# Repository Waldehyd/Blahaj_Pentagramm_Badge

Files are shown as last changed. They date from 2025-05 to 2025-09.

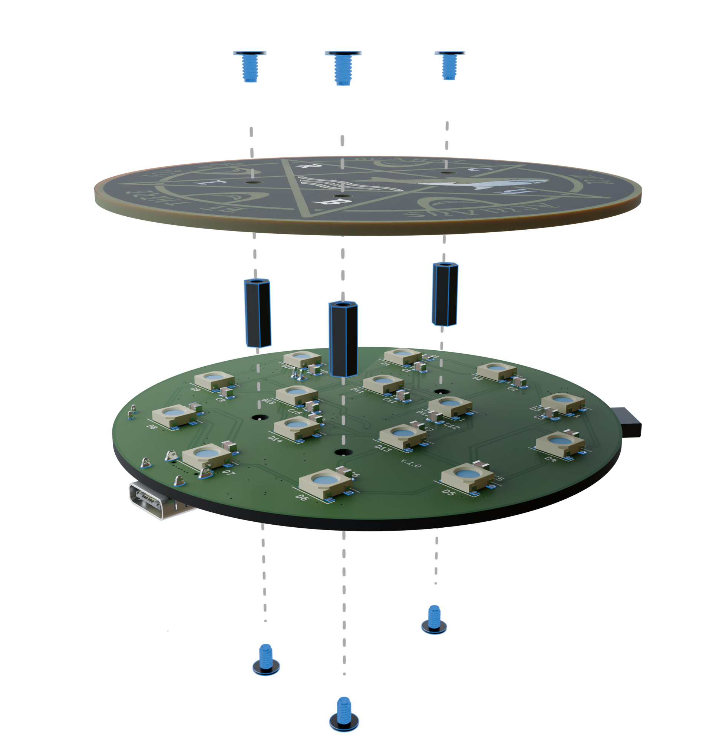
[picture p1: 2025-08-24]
Manual/SetupGuide/Images/Standoffs.png

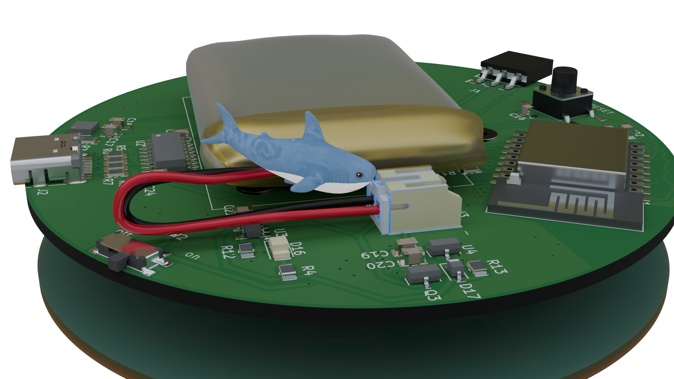
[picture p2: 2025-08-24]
Manual/SetupGuide/Images/AttachLipo.png

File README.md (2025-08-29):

# Blahaj_Pentagramm_Badge

The Shorktagram-Badge features a beautiful PCB-Frontplate backed with 15 individually controllable LEDs, Temperature and Humidity Sensor as well as an optional Motion Sensor. This setup makes it ideal to be used as an air sensor by day and a nightlight by uh... night.

IBOM:
https://htmlpreview.github.io/?https://github.com/Waldehyd/Blahaj_Pentagramm_Badge/blob/main/IBOM/ibom.html

Firmware:

Build WLED (https://github.com/Aircoookie/WLED) using PlatformIO with the following Environment using the Buildflags for BME280 and PIR:

```
[env:d1_mini]
...
build_flags = ${common.build_flags_esp8266} -D USERMOD_BME280 -D USERMOD_PIRSWITCH -D PIR_SENSOR_PIN=13
...
```

Configuration:
```
LED Preferences: 
    -> Length = 15
    -> GPIO = 14
Usermods:
    -> SDA = 4
    -> SCL = 5
    -> Enabled

    Reboot
```

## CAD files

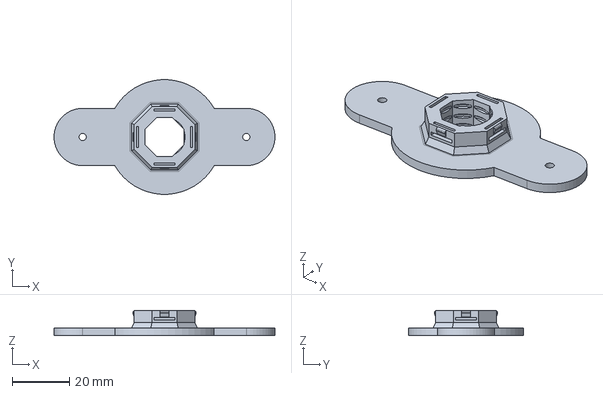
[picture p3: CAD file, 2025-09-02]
Case/mount_multiboard.FCStd
77.0 x 39.9 x 8.80 mm

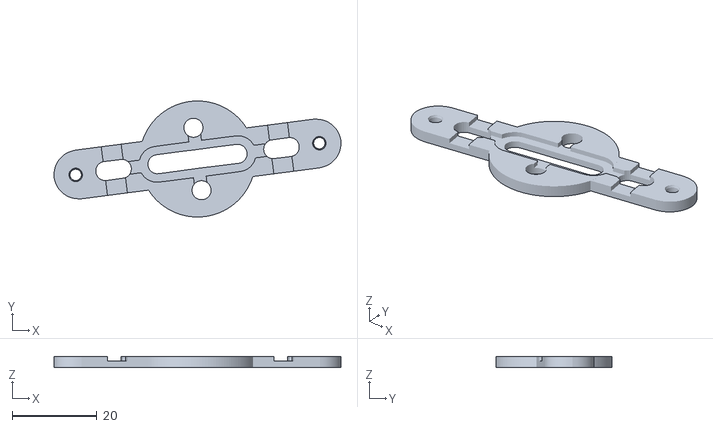
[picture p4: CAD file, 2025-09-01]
Case/STL/Mount.stl
67.6 x 27.3 x 2.51

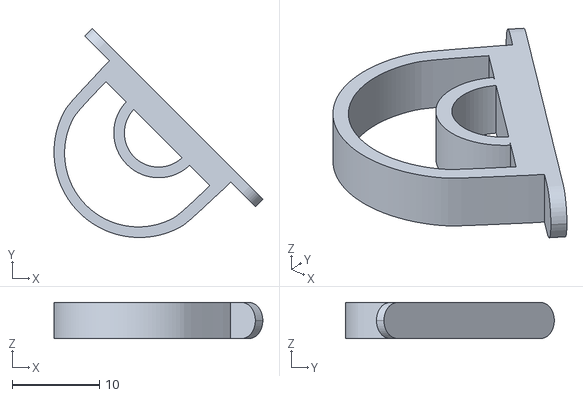
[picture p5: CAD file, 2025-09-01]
Case/STL/Hook.stl
23.9 x 23.9 x 4.15

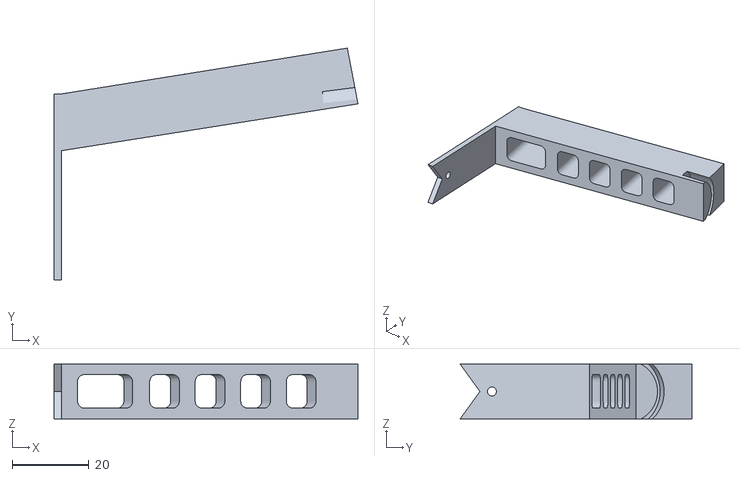
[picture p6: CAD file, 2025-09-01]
Case/STL/Stand_2.stl
79.1 x 60.3 x 14.3

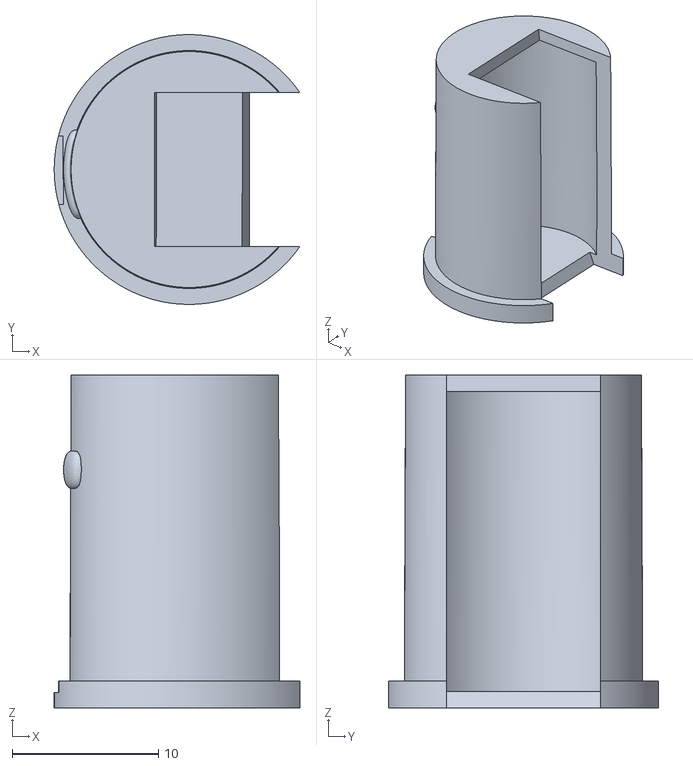
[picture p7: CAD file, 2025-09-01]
Case/STL/PIR_1.stl
16.8 x 18.4 x 22.8

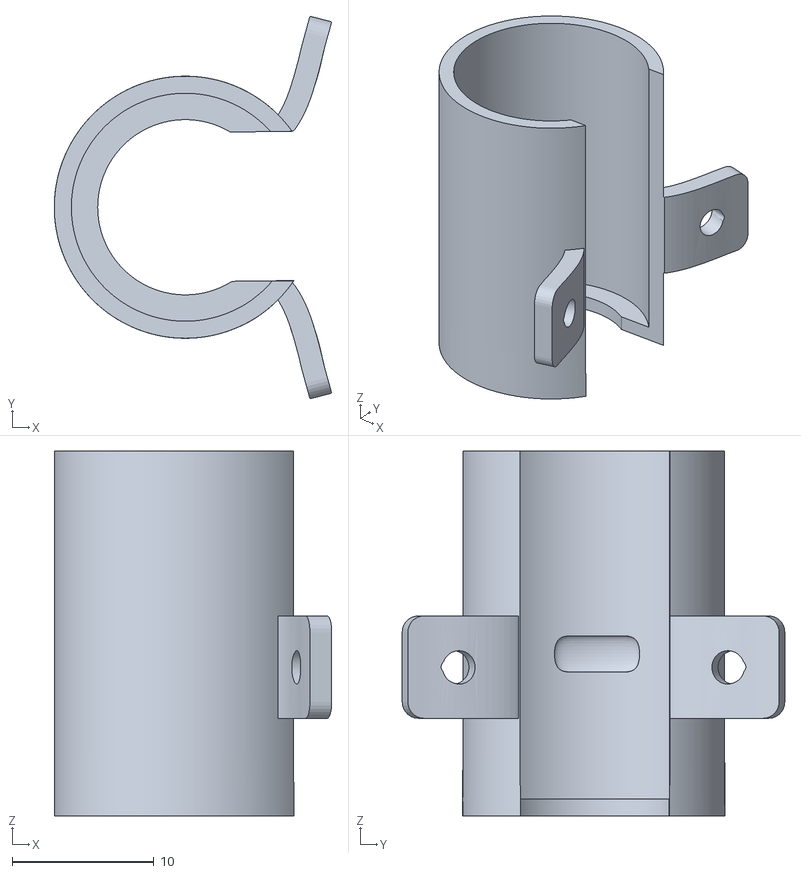
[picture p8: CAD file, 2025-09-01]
Case/STL/PIR_2.stl
19.5 x 26.9 x 25.7

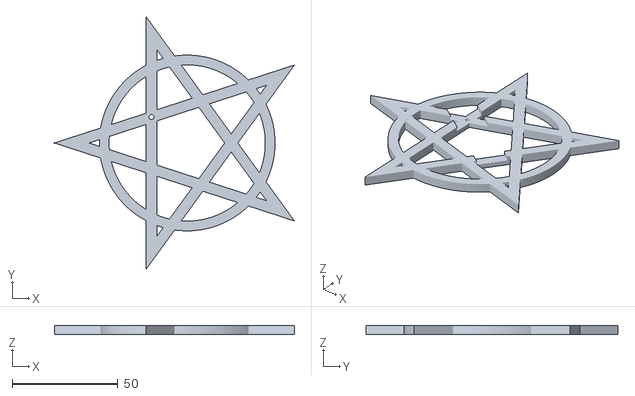
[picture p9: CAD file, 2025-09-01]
Case/STL/Stand_1.stl
113.4 x 119.2 x 4.20

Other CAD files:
Case/STL/mount_multiboard.stl

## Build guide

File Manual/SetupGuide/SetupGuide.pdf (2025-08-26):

Table of Contents

# The Shorktagram Badge

Version 1.0.0 | 2025-08-25 | MIT

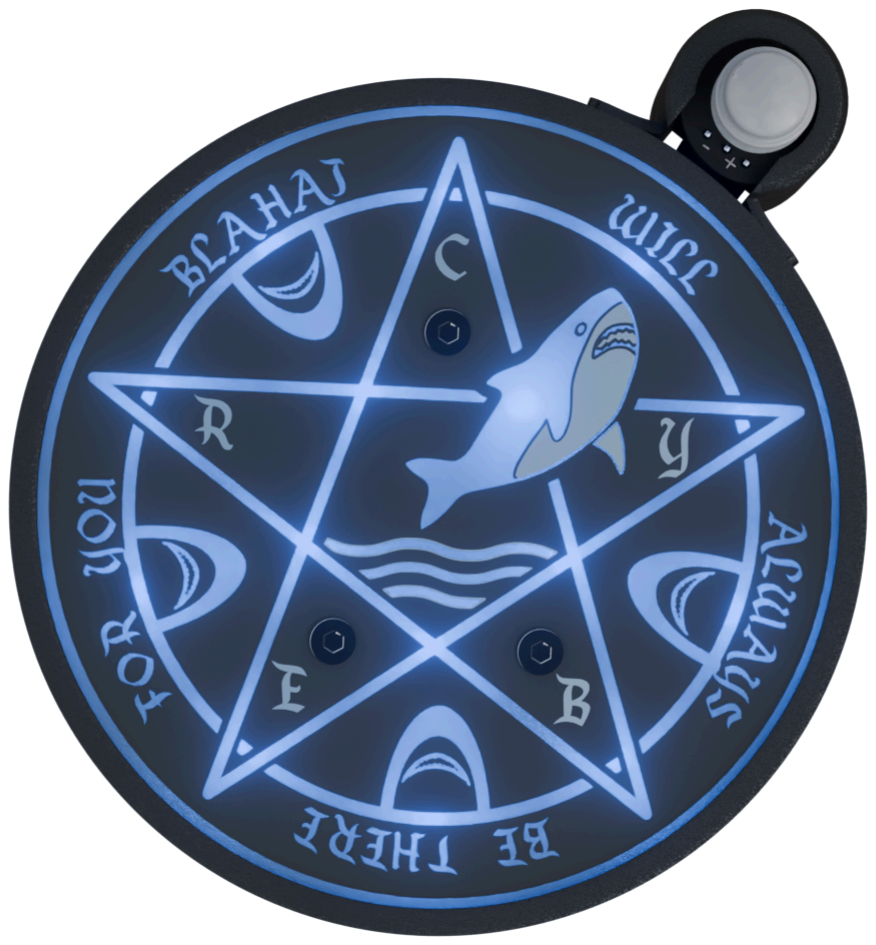
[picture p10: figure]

The Shorktagram-Badge features a beautiful PCB-Frontplate backed with 15 individually controllable LEDs, Temperature and Humidity Sensor as well as an optional Motion Sensor. This setup makes it ideal to be used as an air sensor by day and a nightlight by uh… night.

### Table of Contents

IV.4 Home Assistant Integration and

IV.5 Loading your light settings at

## Part I Assembly Part 1: PCB

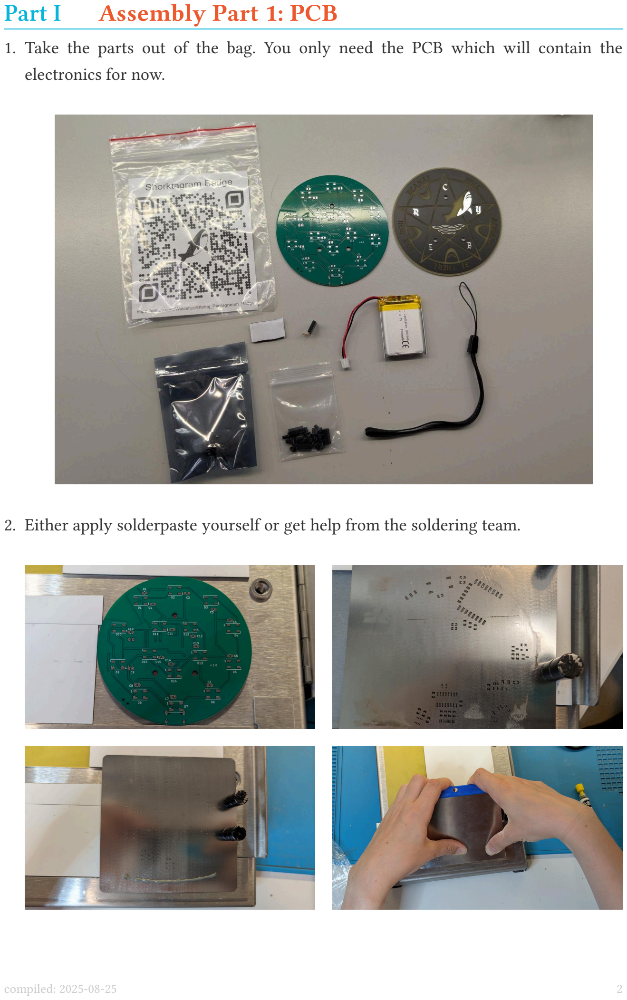
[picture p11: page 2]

1. Take the parts out of the bag. You only need the PCB which will contain the electronics for now.
2. Either apply solderpaste yourself or get help from the soldering team.
compiled: 2025-08-25 | 2

I Assembly Part 1: PCB

3. Open the IBOM of the repo (PCB/PCB_Back/bom/ibom.html) and start placing the parts with a pair of tweezers. The parts in the box are sorted in the order in which they are needed.
4. When you are done with the first side, put the PCB in the oven and bake it for the first time.

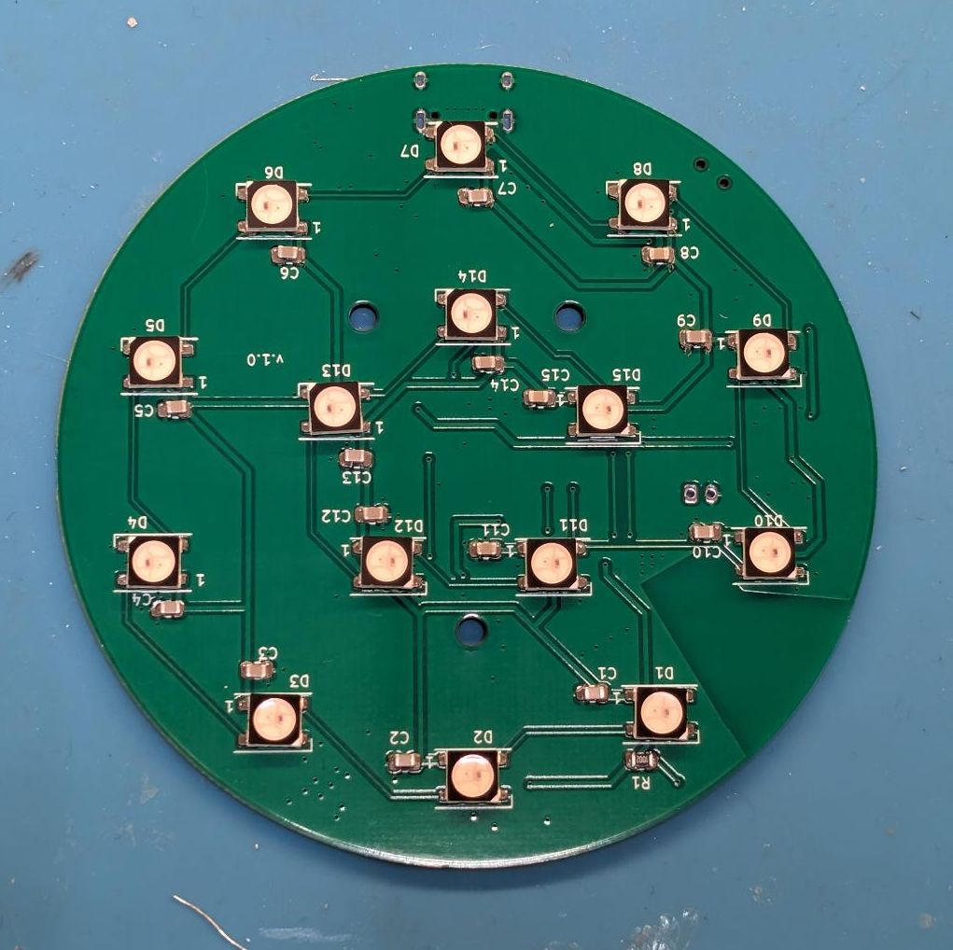
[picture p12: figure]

5. Wait until the PCB has cooled of and continue placing the parts on the other side. Please skip the hand-solder parts for now.
compiled: 2025-08-25 | 3

I Assembly Part 1: PCB

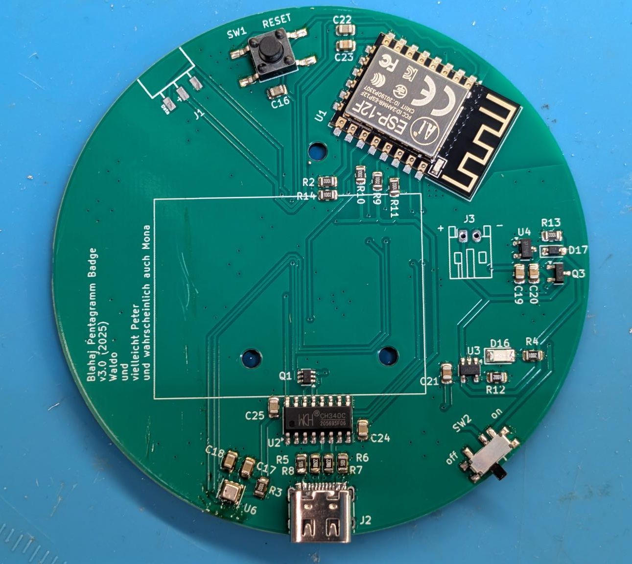
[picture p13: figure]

6. Bake the other side of the PCB.
7. Take a look at the PCB and search for shorts and errors on the placed parts. Remediate these errors before you continue. If needed, get help from your local Shorktagram dealer.
8. Hand-solder the last two parts onto the PCB. Solder on the USB-C connector legs. DO THIS BEFORE YOU PLUG IN A USB CABLE.
9. Connect your PCB to your computer and see if the ESP shows up. If so: Congratulation, you are done with the hardest part. Please return your empty tray to the workshop-hosts. If you want, they can also flash your Shorktagram-Badge.
compiled: 2025-08-25 | 4

## Part II Assembly Part 2: Case

1. Take the little bag with the screws and the standoffs. Screw the faceplate onto the PCB with the standoffs in between.

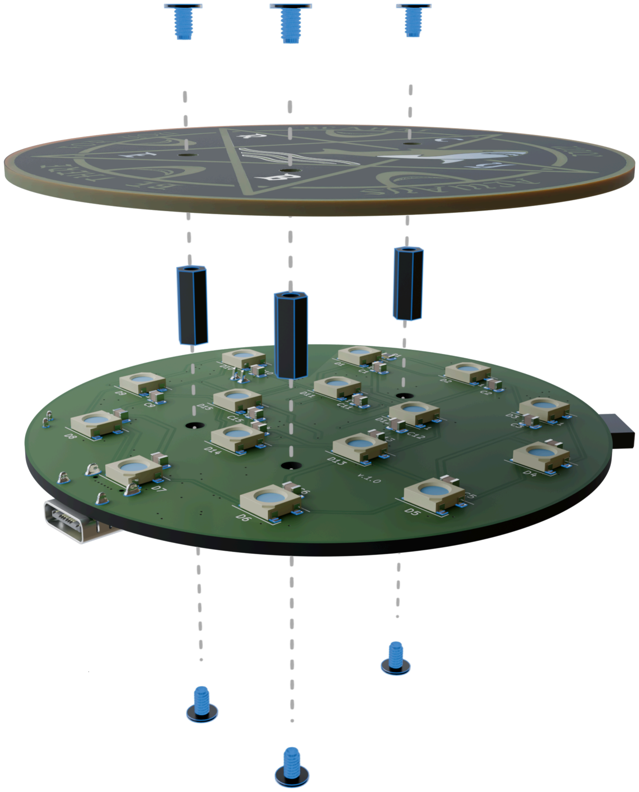
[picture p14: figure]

2. Next you will need the battery and the velcro-tape. If you are planning on using the battery, apply one of the sides of the velcro to the battery-box-area on the PCB and the other side to the battery.

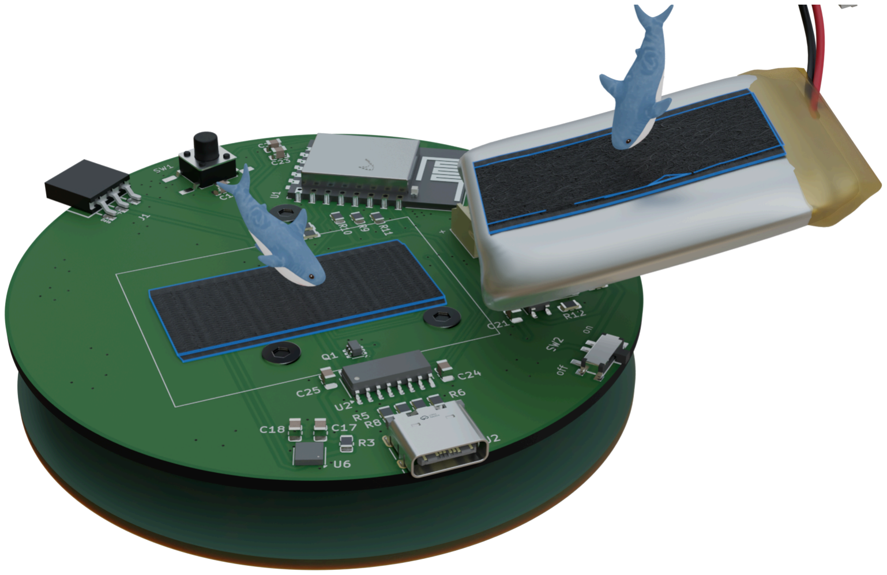
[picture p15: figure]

compiled: 2025-08-25 | 5

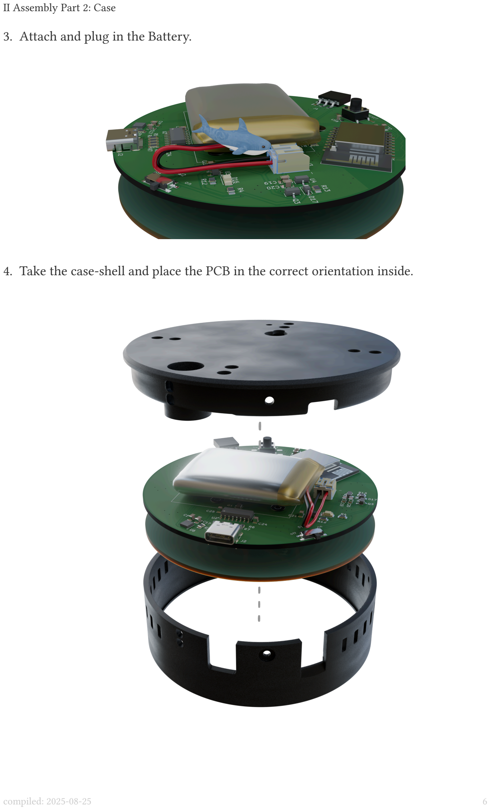
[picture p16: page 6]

II Assembly Part 2: Case

3. Attach and plug in the Battery.
4. Take the case-shell and place the PCB in the correct orientation inside.
compiled: 2025-08-25 | 6

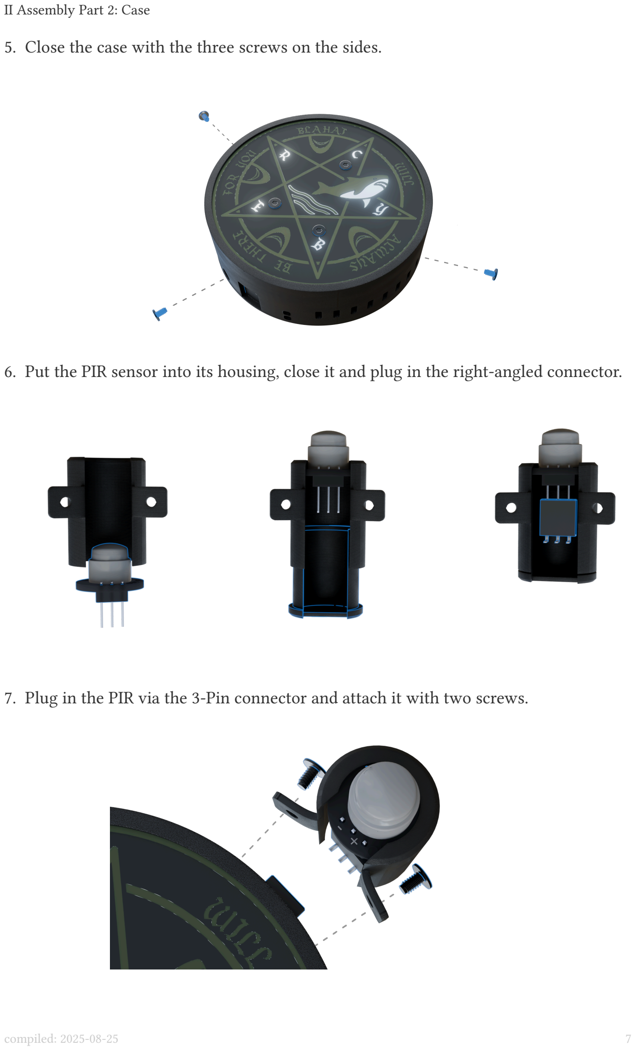
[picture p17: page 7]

II Assembly Part 2: Case

5. Close the case with the three screws on the sides.
6. Put the PIR sensor into its housing, close it and plug in the right-angled connector.
7. Plug in the PIR via the 3-Pin connector and attach it with two screws.
compiled: 2025-08-25 | 7

II Assembly Part 2: Case

8. Screw in two screws into the mounting plate (towards the side with cutouts). Optionally, push through the hook. You attach the mounting plate by pushing and turning them in the oblong holes.

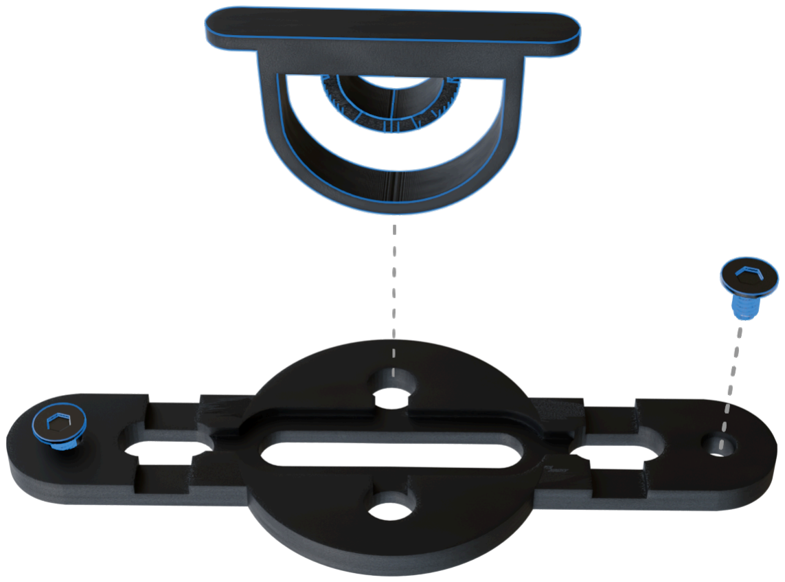
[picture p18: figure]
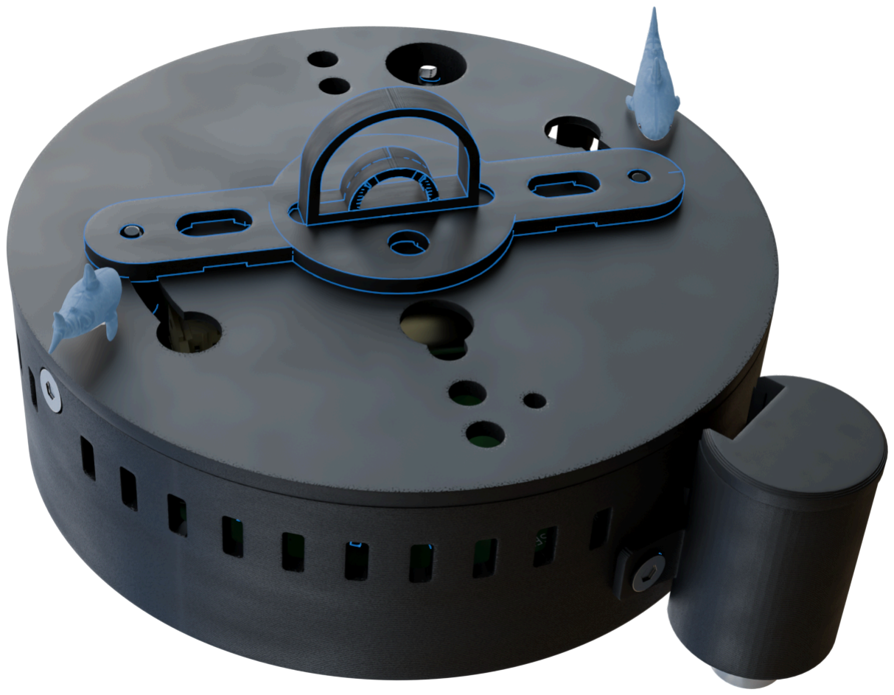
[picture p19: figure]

compiled: 2025-08-25 | 8

## Part III Flashing the Firmware

Prerequisites: A computer running VSCode with the Platform.io extension installed.

The Shorktagram-Badge is powered by WLED. As we use Usermods to support the PIR and the BME280, it’s necessary to build WLED from source. This involves the following steps:

1. Clone or Download the latest Version of WLED from Github (https://github.com/wled/WLED) (https://github.com/wled/WLED)
2. Replace the platformio.ini by the one in the /Firmware folder of the Shorktagram-Badge Repository (https://github.com/Waldehyd/Blahaj_Pentagramm_Badge)
3. Connect the Badge to your computer via USB (if it’s not recognized as a serial device, it’s likely a soldering problem)
4. Open the WLED-Folder in VSCode
5. Choose the correct serial port of your Badge (if multiple devices are connected) and then hit upload!
compiled: 2025-08-25 | 9

## Part IV Configuring WLED

### IV.1 Default Values

After flashing, the 15 LEDs should light up instantly. The following values should be preconfigured and (if correct) should not be edited:

SDA | 4
SCL | 5
PIRPIN | 13
LEDPIN | 14
LEDCOUNT | 15

### IV.2 Wifi-Setup

By default, WLED opens up a Wifi-AP to access the Webinterface. The default password is “wled1234”. To integrate your Badge into your local Wifi, hit “WiFi Setup” and enter your credentials. You can also change the password of the AP from there as well (we recommend this to avoid mix-ups, i.e. connecting to the wrong device).

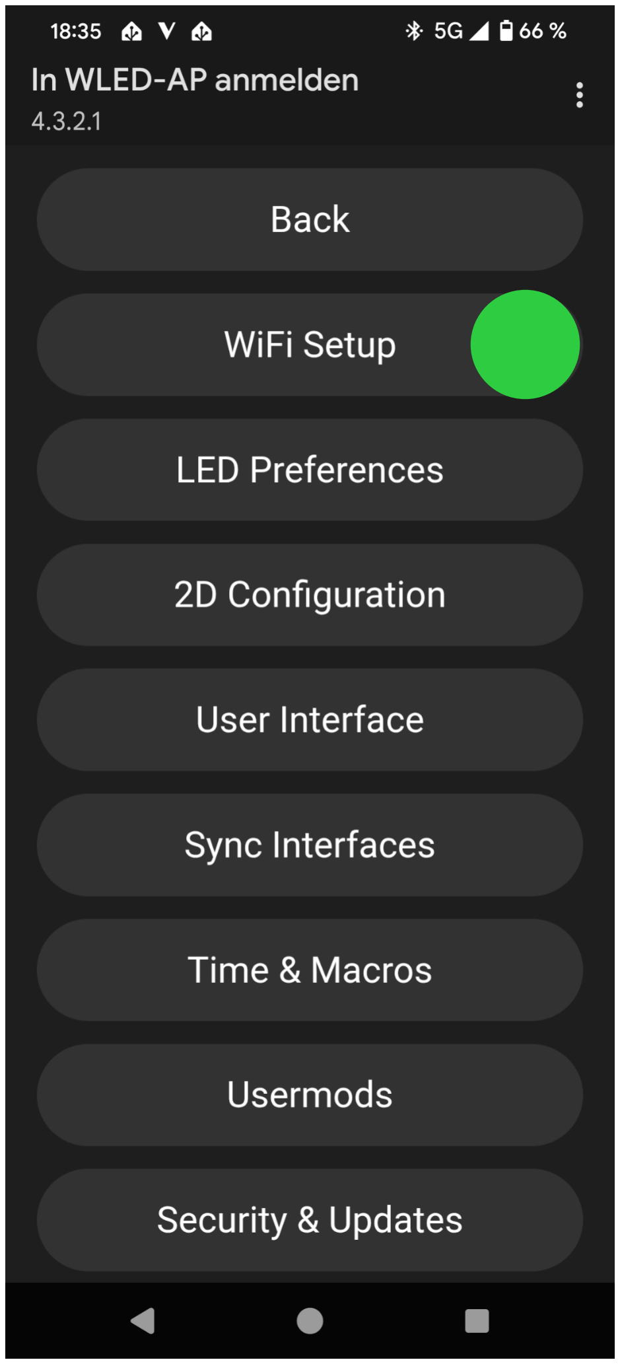
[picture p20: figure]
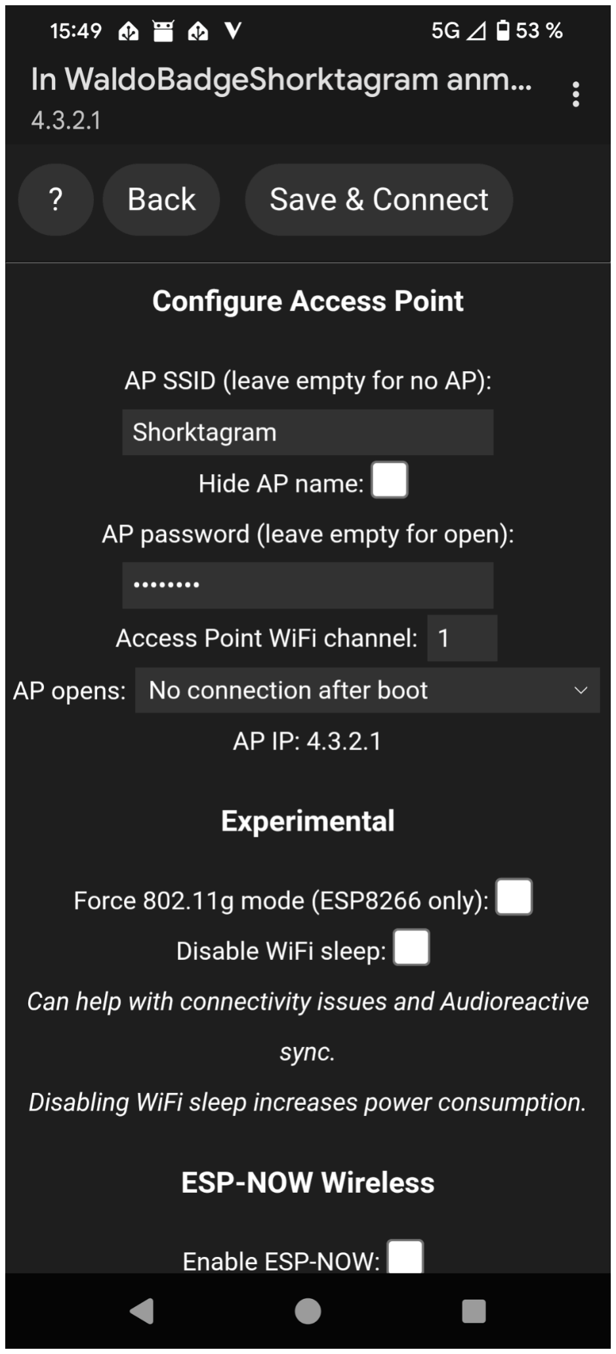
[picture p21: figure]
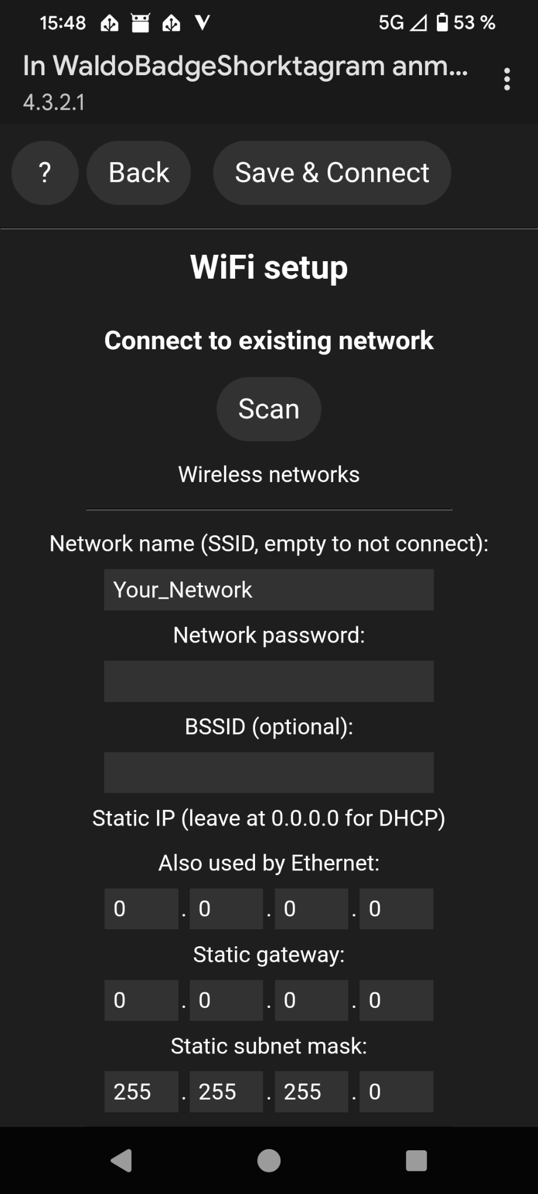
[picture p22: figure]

compiled: 2025-08-25 | 10

IV Configuring WLED

### IV.3 Enable Usermods

Back in the Settings, go to “Usermods”. From there, you can enable the BME280 and/or the PIR.

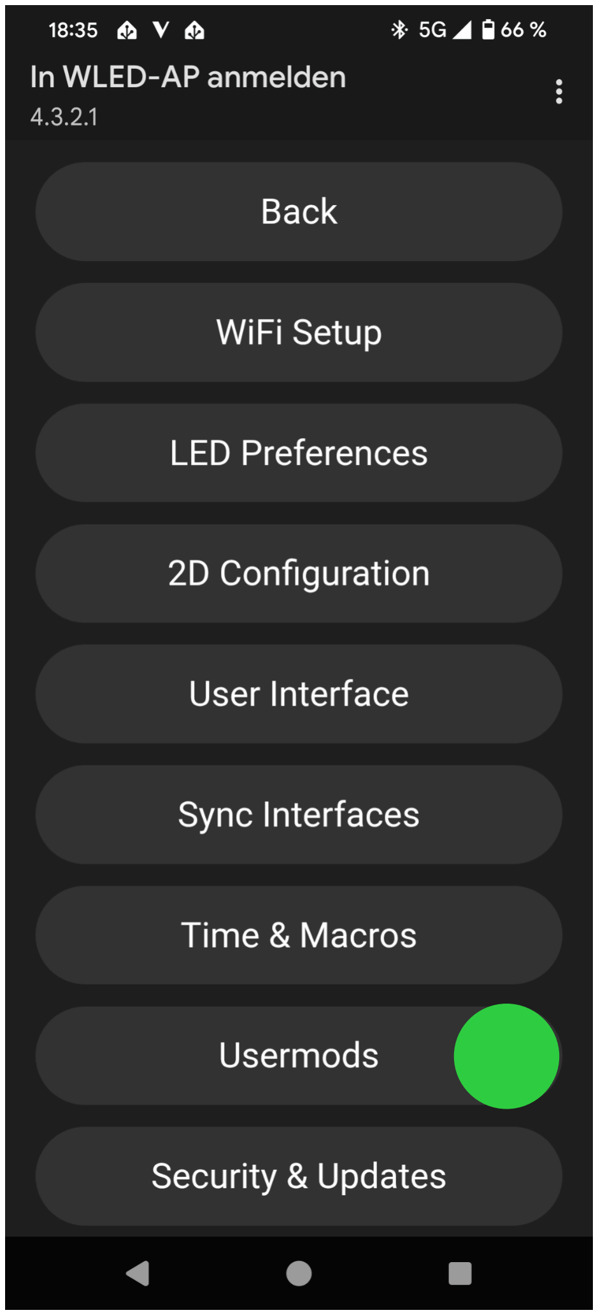
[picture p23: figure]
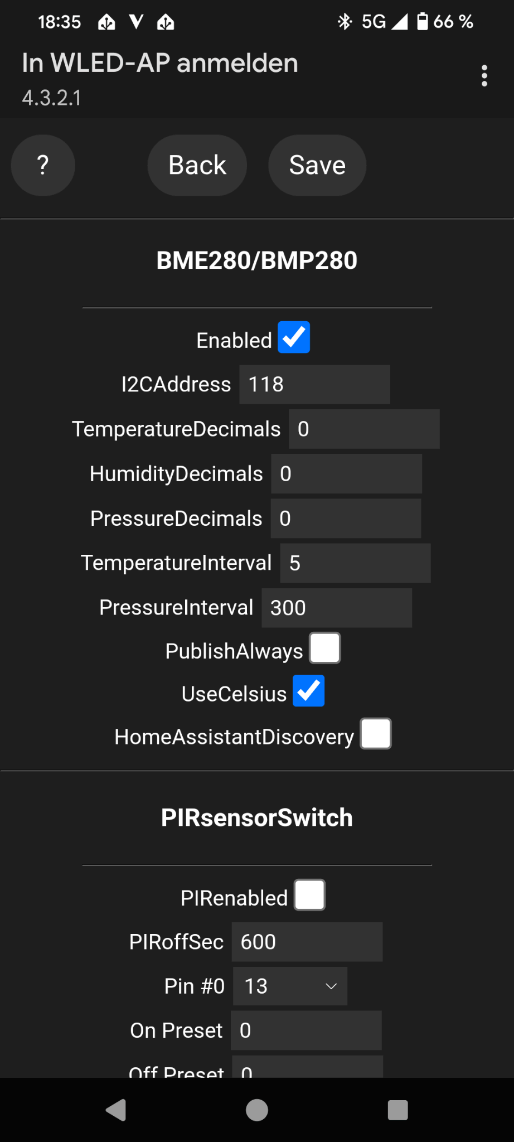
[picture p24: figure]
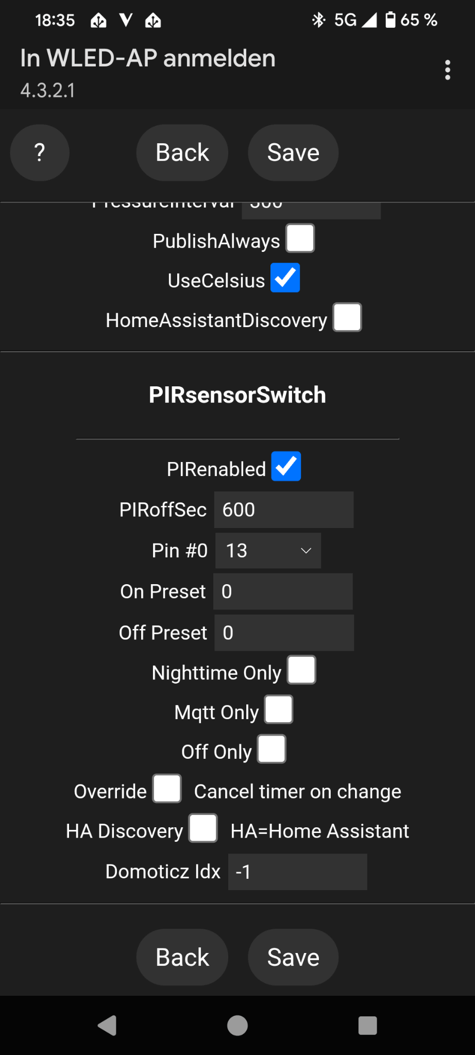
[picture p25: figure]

The settings are mostly self-explanatory (famous last words I know). If you want to use Home Assistant, tick “HomeAssistantDiscovery” on the BME and “HA Discovery” on the PIR. The PIR can be used in MQTT-Only Mode, which exposes the PIR but doesn’t turn off the LEDs automatically. The “PIROffSec” sets the delay between the moment when no motion was detected and the LEDs turning off.
If you want access the values without using Home Assistant, head over to the LED Configuration section.

### IV.4 Home Assistant Integration and MQTT

After the Badge was added to your Wifi, it’s usually autodiscovered by HA and can be configured via the WLED-Integration. If not, manually install the integration manually and enter the local IP of your Badge.

compiled: 2025-08-25 | 11

IV Configuring WLED | IV.4 Home Assistant Integration and MQTT

To access the values from the BME280 and the PIR, it’s necessary to configure MQTT in WLED as well. If you use Home Assistant, you probably have the Mosquitto MQTT Broker installed already. Head over to “Sync Interfaces”, scroll down to “MQTT” and enter the Broker IP (likely your Home Assistant IP) as well as Username and Password. Afterwards, restart WLED and you should find the published values in a MQTT-Device called “WLED”.

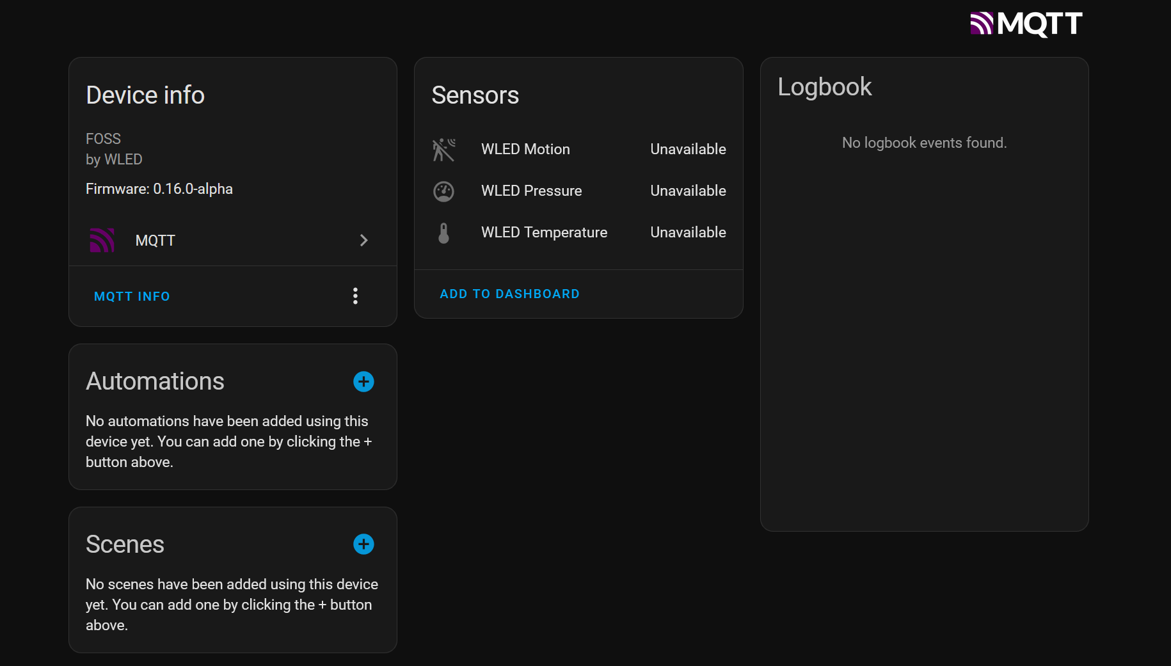
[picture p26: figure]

compiled: 2025-08-25 | 12

IV Configuring WLED

### IV.5 Loading your light settings at startup

WLED does not save your light settings without being explicitly. After setting up your colors/effects, you need to save them as a preset. If you want a preset to be loaded at startup, enter the ID in the LED Preferences under “Defaults -> Apply preset X”.

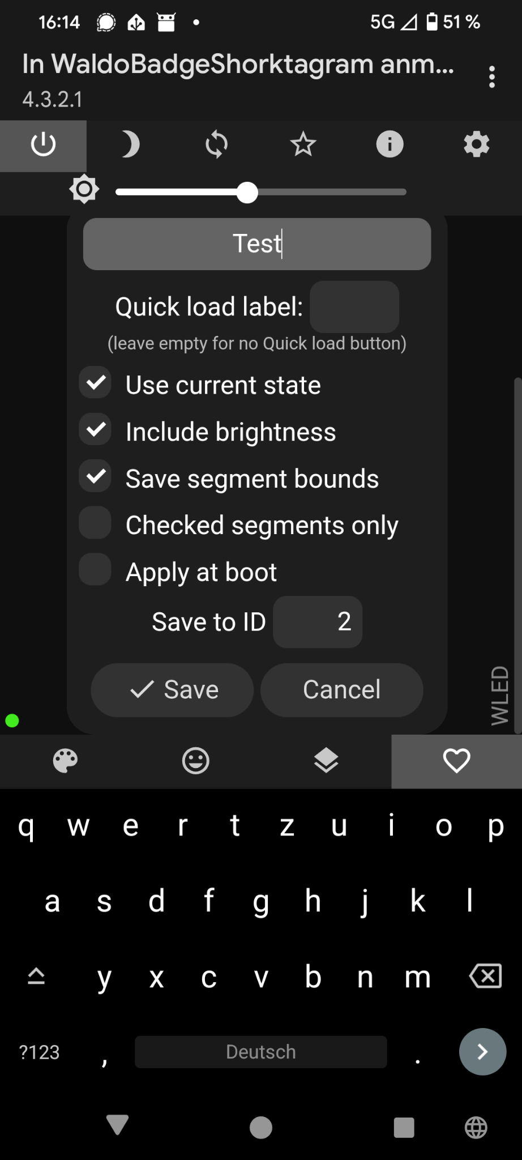
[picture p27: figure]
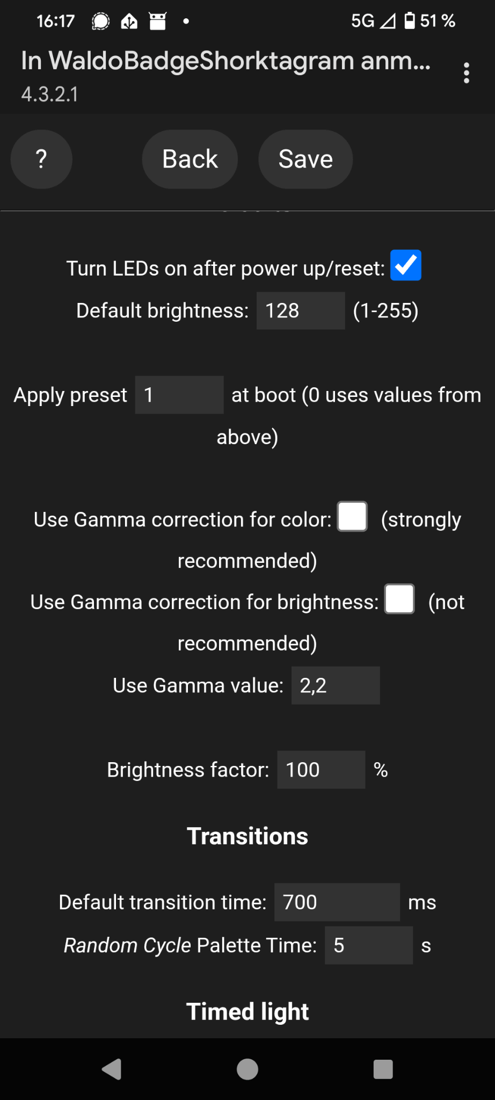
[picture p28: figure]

compiled: 2025-08-25 | 13

## Part V Notes on Usage

As running the LEDs for a while results in the Badge heating up quite a bit, the sensor readings from the BME280 become unreliable for air measurements. As such, it’s recommended to use the BME280 for setups where the LEDs aren’t used continuously, e.g. when using the PIR in conjunction with a nighttime timer for the pathway to your bathroom.

compiled: 2025-08-25 | 14

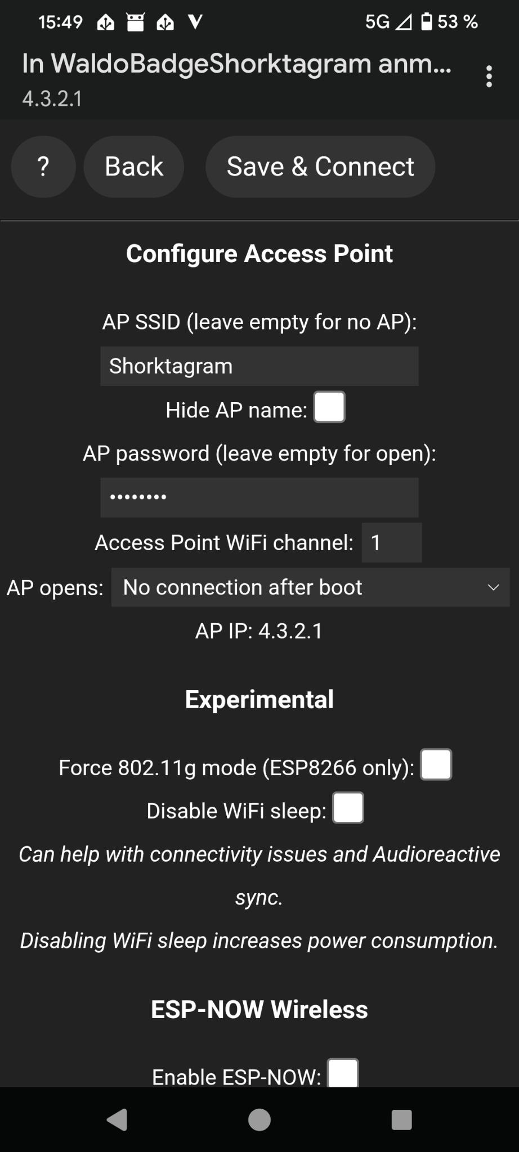
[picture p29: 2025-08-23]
Manual/SetupGuide/Images/APPass.png

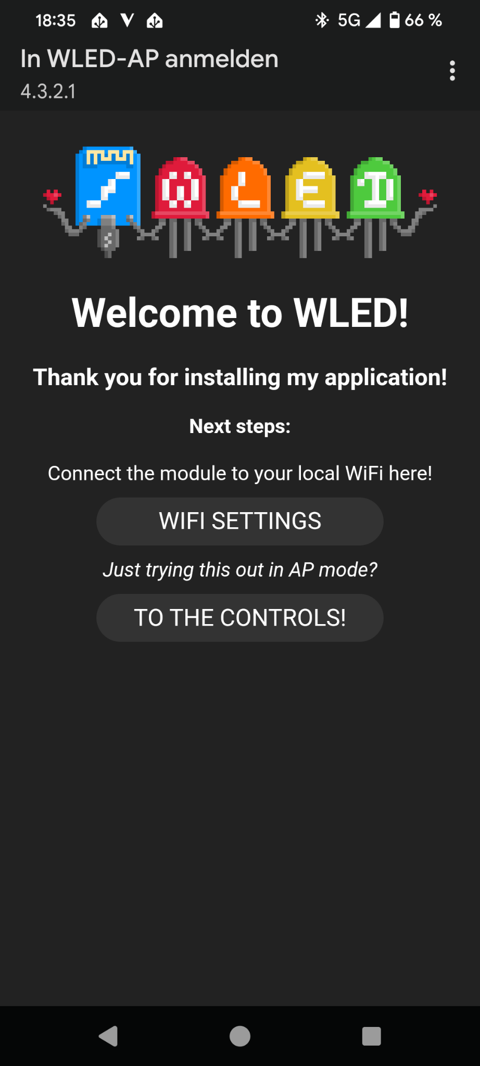
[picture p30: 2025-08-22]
Manual/SetupGuide/Images/WLEDWelcomeScreen.png

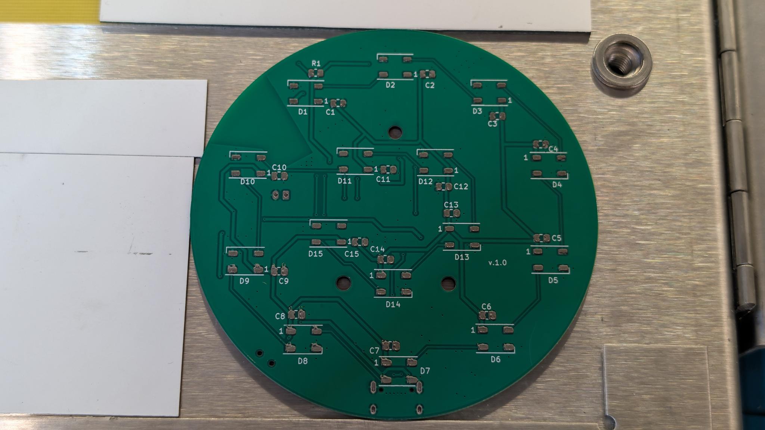
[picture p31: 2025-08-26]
Manual/SetupGuide/Images/Real/Clamp.jpeg

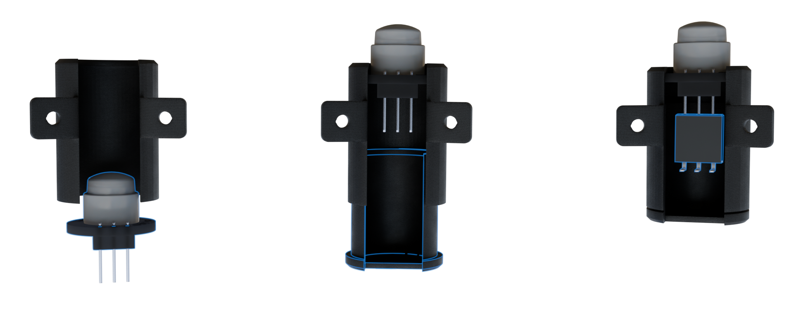
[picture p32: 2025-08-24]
Manual/SetupGuide/Images/AssembleSensor.png

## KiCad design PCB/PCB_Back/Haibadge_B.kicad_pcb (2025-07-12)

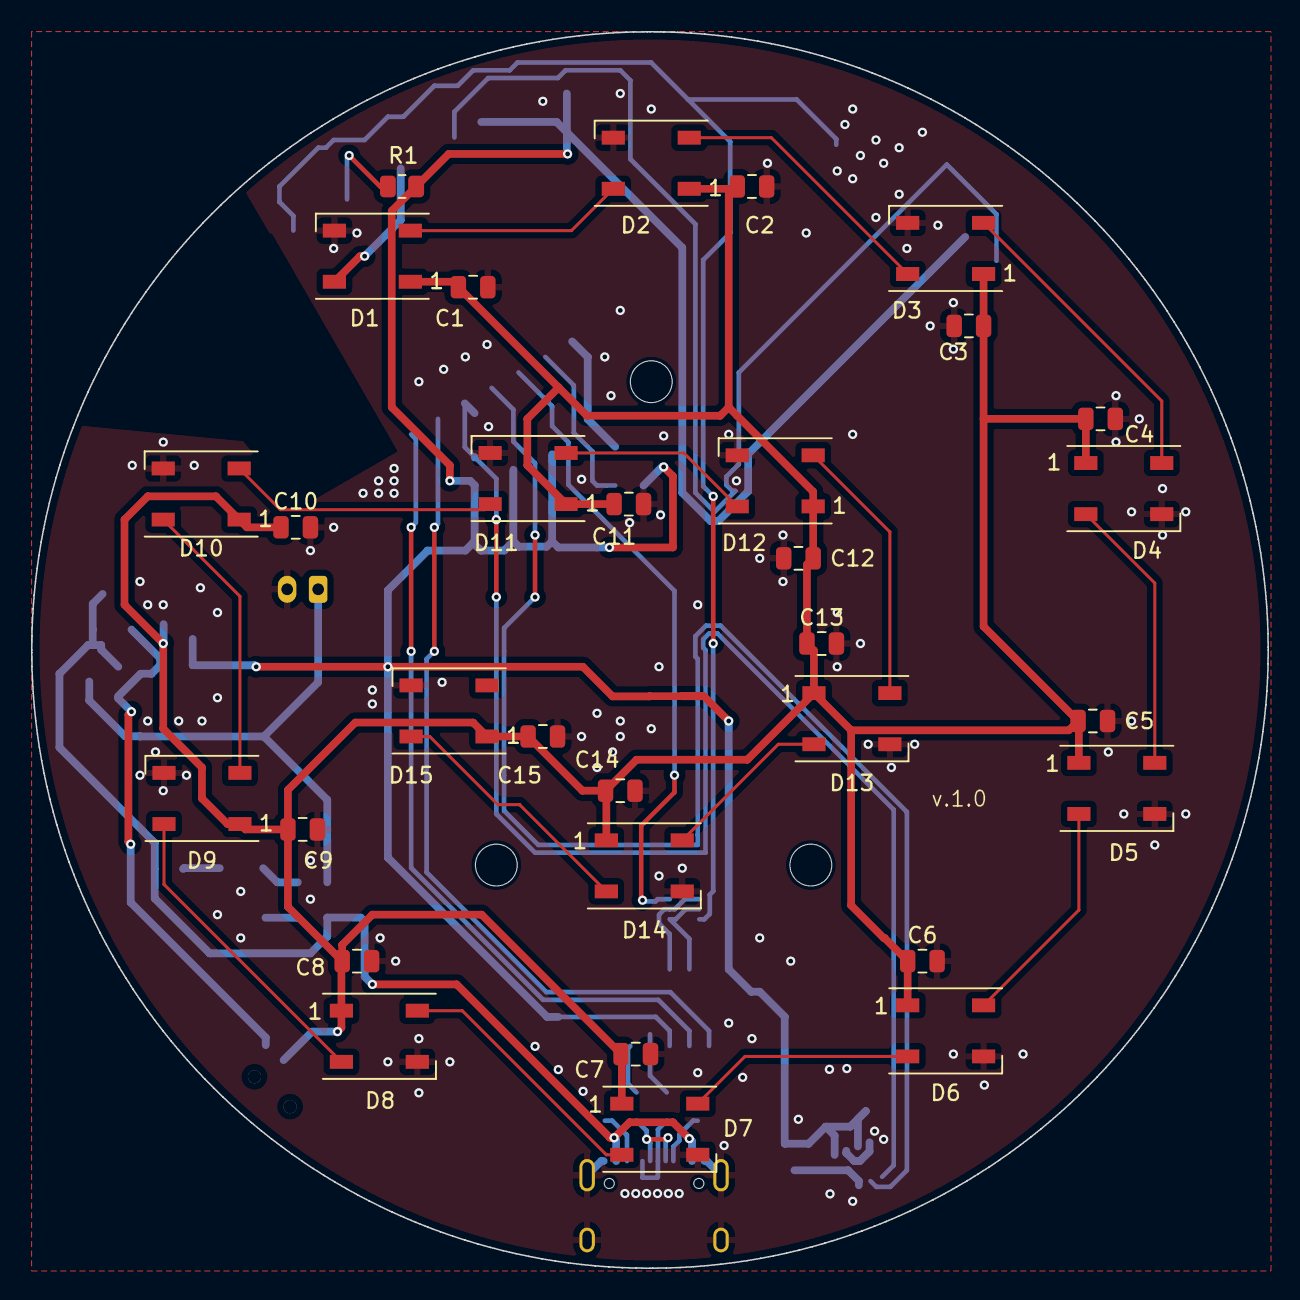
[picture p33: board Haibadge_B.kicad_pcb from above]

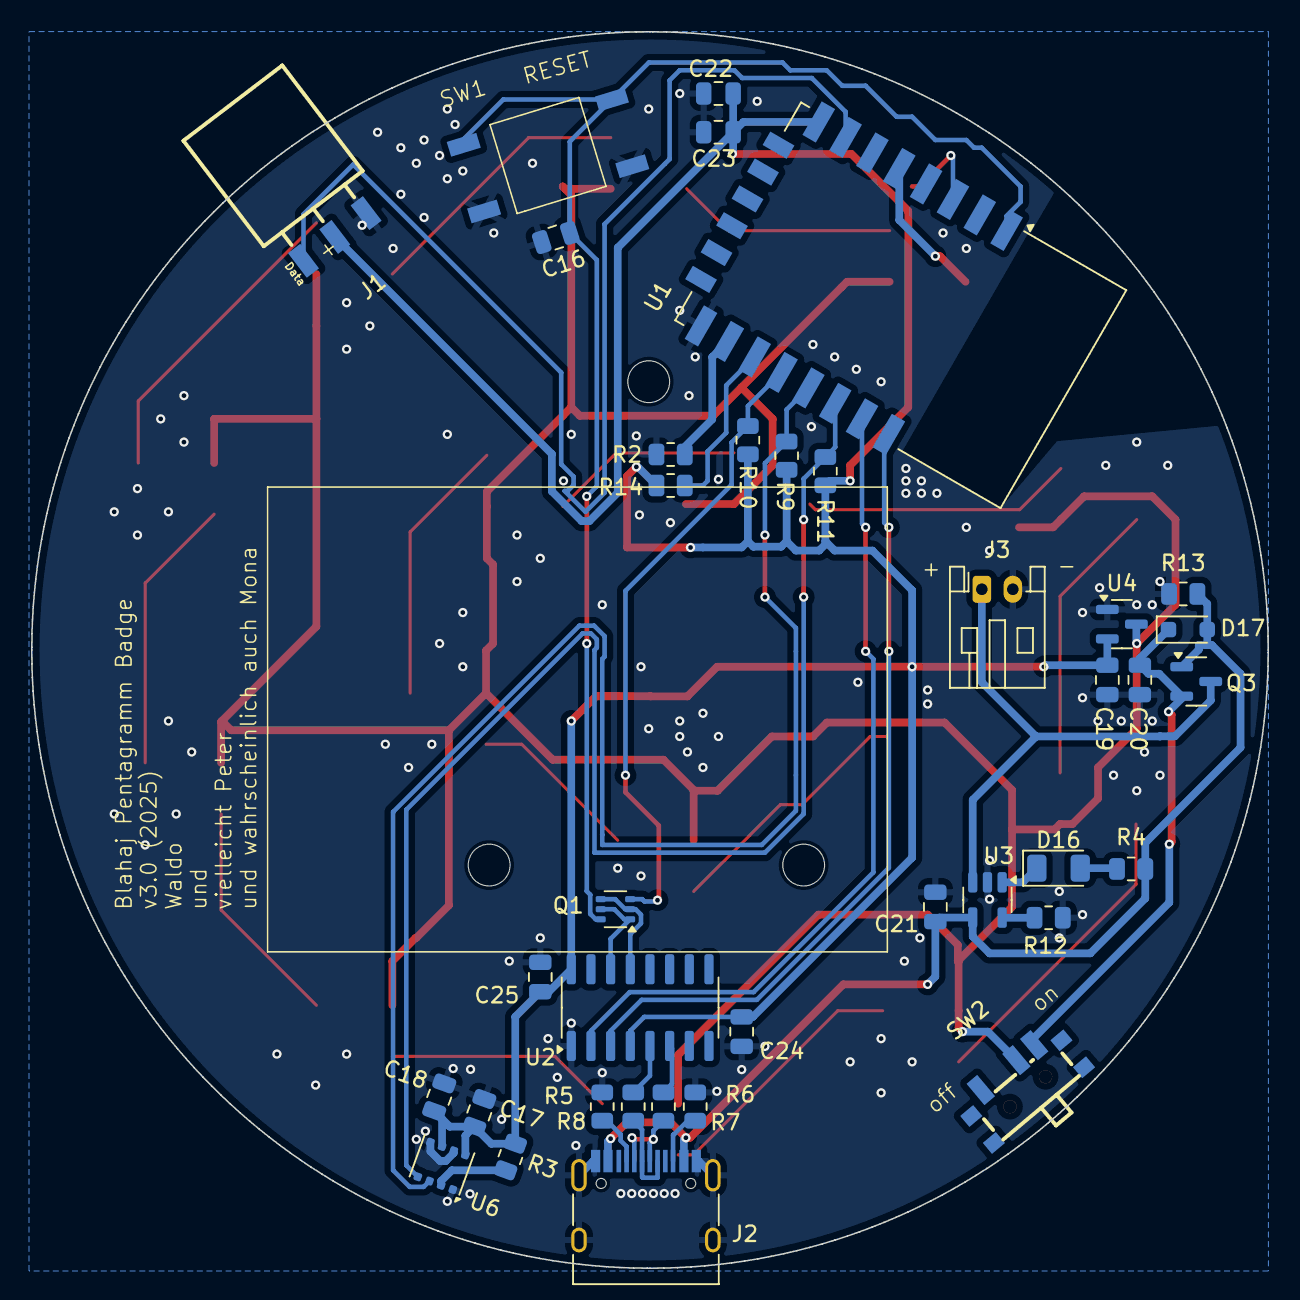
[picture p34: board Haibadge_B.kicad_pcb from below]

Board: 2 copper layers, 79.8 x 79.8 mm, 71 parts (37 on the bottom side), 43 nets.

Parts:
C1, C2, C3, C4, C5, C6, C7, C8, C9, C10, C11, C12, C13, C14, C15, C16, C17, C18, C22, C24, C25: 100nF; C_0805_2012Metric
C19, C20, C23: 1uF; C_0805_2012Metric
C21: 4.7uF; C_0805_2012Metric
D1, D2, D3, D4, D5, D6, D7, D8, D9, D10, D11, D12, D13, D14, D15: WS2812B; LED_WS2812B_PLCC4_5.0x5.0mm_P3.2mm
D16: LED; LED_1206_3216Metric
D17: D; D_SOD-323_HandSoldering
H1, H2, H3: MountingHole; MountingHole_2.7mm_M2.5
J1: Sensor connector; HDR-SMD_3P-P2.54-H-F-L11.5
J2: USB_C_Receptacle_USB2.0; USB_C_Receptacle_HRO_TYPE-C-31-M-12
J3: Lipo connector; JST_PH_S2B-PH-K_1x02_P2.00mm_Horizontal
Q1: UMH3N; SOT-363_SC-70-6
Q3: Q_PMOS_GSD; SOT-23
R1, R2, R3, R9, R10, R11, R13, R14: 10k; R_0805_2012Metric
R4, R12: 2k; R_0805_2012Metric
R5, R6: 5k1; R_0805_2012Metric
R7, R8: 22; R_0805_2012Metric
SW1: SW_Push_Dual; KH-6X6X6H-STM
SW2: SW_PWR; SW-SMD_MK-12C02-G025
U1: ESP-12E
U2: CH340C; SOIC-16_3.9x9.9mm_P1.27mm
U3: MCP73831-2-OT; SOT-23-5
U4: MCP1700x-330xxTT; SOT-23
U6: BME680; Bosch_LGA-8_3x3mm_P0.8mm_ClockwisePinNumbering

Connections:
+3V3: C17.1, C18.1, C19.1, C22.1, C23.1, C24.1, C25.1, J1.2, R1.1, R3.2, R9.2, R10.2, R11.2, R14.2, U1.8 (VCC), U2.4 (V3), U2.16 (VCC), U4.2 (VO), U6.6 (VDDIO), U6.8 (VDD)
+5V: C21.1, D17.2 (A), J2.A4 (VBUS), J2.A9 (VBUS), J2.B4 (VBUS), J2.B9 (VBUS), Q3.1 (G), R4.2, R13.2, U3.4 (V_{DD})
+BATT: J3.1, Q3.3 (D), U3.3 (V_{BAT})
/WS2812B/WS2812B: D1.4 (DIN), U1.5 (GPIO14)
/uC/D+: J2.A6 (D+), J2.B6 (D+), R8.2
/uC/D-: J2.A7 (D-), J2.B7 (D-), R7.1
/uC/RD+: R8.1, U2.5 (UD+)
/uC/RD-: R7.2, U2.6 (UD-)
DTR: Q1.2 (B1), Q1.4 (E2), U2.13 (~DTR)
GND: C1.2, C2.2, C3.2, C4.2, C5.2, C6.2, C7.2, C8.2, C9.2, C10.2, C11.2, C12.2, C13.2, C14.2, C15.2, C16.2, C17.2, C18.2, C19.2, C20.2, C21.2, C22.2, C23.2, C24.2, C25.2, D1.3 (VSS), D2.3 (VSS), D3.3 (VSS), D4.3 (VSS), D5.3 (VSS), D6.3 (VSS), D7.3 (VSS), D8.3 (VSS), D9.3 (VSS), D10.3 (VSS), D11.3 (VSS), D12.3 (VSS), D13.3 (VSS), D14.3 (VSS), D15.3 (VSS), J1.1, J2.A1 (GND), J2.A12 (GND), J2.B1 (GND), J2.B12 (GND), J2.S1 (SHIELD), J3.2, R2.2, R5.2, R6.1, R12.1, R13.1, SW1.3, SW1.4, U1.15 (GND), U2.1 (GND), U3.2 (V_{SS}), U4.1 (GND), U6.1 (GND), U6.5 (SDO), U6.7 (GND)
GPIO0: Q1.3 (C2), R10.1, U1.18 (GPIO0)
unnamed: D1.2 (DOUT), D2.4 (DIN)
unnamed: D2.2 (DOUT), D3.4 (DIN)
unnamed: D3.2 (DOUT), D4.4 (DIN)
unnamed: D4.2 (DOUT), D5.4 (DIN)
unnamed: D5.2 (DOUT), D6.4 (DIN)
unnamed: D6.2 (DOUT), D7.4 (DIN)
unnamed: D7.2 (DOUT), D8.4 (DIN)
unnamed: D8.2 (DOUT), D9.4 (DIN)
unnamed: D9.2 (DOUT), D10.4 (DIN)
unnamed: D10.2 (DOUT), D11.4 (DIN)
unnamed: D11.2 (DOUT), D12.4 (DIN)
unnamed: D12.2 (DOUT), D13.4 (DIN)
unnamed: D13.2 (DOUT), D14.4 (DIN)
unnamed: D14.2 (DOUT), D15.4 (DIN)
unnamed: D16.2 (A), R4.1
unnamed: D16.1 (K), U3.1 (STAT)
unnamed: C20.1, D17.1 (K), Q3.2 (S), SW2.3 (C)
unnamed: J2.A5 (CC1), R5.1
unnamed: J2.B5 (CC2), R6.2
unnamed: R1.2, U1.3 (EN)
unnamed: U1.22 (GPIO1/TXD), U2.3 (RXD)
unnamed: R14.1, U1.17 (GPIO2)
unnamed: U1.21 (GPIO3/RXD), U2.2 (TXD)
unnamed: R9.1, U1.19 (GPIO4), U6.3 (SDI)
unnamed: R11.1, U1.20 (GPIO5), U6.4 (SCK)
unnamed: R2.1, U1.16 (GPIO15)
unnamed: R12.2, U3.5 (PROG)
unnamed: R3.1, U6.2 (CSB)
RST: C16.1, Q1.6 (C1), SW1.1, SW1.2, U1.1 (~RST)
RTS: Q1.1 (E1), Q1.5 (B2), U2.14 (~RTS)
Sensor: J1.3, U1.7 (GPIO13)
VCC: C1.1, C2.1, C3.1, C4.1, C5.1, C6.1, C7.1, C8.1, C9.1, C10.1, C11.1, C12.1, C13.1, C14.1, C15.1, D1.1 (VDD), D2.1 (VDD), D3.1 (VDD), D4.1 (VDD), D5.1 (VDD), D6.1 (VDD), D7.1 (VDD), D8.1 (VDD), D9.1 (VDD), D10.1 (VDD), D11.1 (VDD), D12.1 (VDD), D13.1 (VDD), D14.1 (VDD), D15.1 (VDD), SW2.2 (B), U4.3 (VI)

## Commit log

2025-08-01 Update Case to latest (Mounting Plate, Hook)
2025-08-22 Add current state of SetupGuide
2025-08-26 Update Case and STL (not correclty orientated yet)
    [CaseV2_1.stl, CaseV2_2.stl, Hook.stl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]
2025-09-01 Update with correct STL sizes and rotations, added Stand
    [Hook.stl, Mount.stl, PIR_1.stl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]
2025-09-02 Add a Multiboard compatible mount
    [mount_multiboard.FCStd, mount_multiboard.stl]
